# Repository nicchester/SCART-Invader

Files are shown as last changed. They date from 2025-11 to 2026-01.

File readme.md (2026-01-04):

# SCART Invader 

An open-hardware RGB SCART multiplexer with features:

- Auto-detection of a video signal on CVBS, CSYNC, YPbPr, or S-Video
- Aspect ratio (pin 8) and RGB/Composite blanking (pin 16) control 
- Support for CVBS -> CSYNC with LM1881 on board (switched in by a relay) 
- IR remote control 
- Fully isolated relay mux design 
- 100% Through-hole design for tedious hand assembly 
- Ultra-compact design 
- Enclosure printable on most home 3D printers 
- 2-layer PCB design for cheap manufacture by your favourite PCB fabricator

---

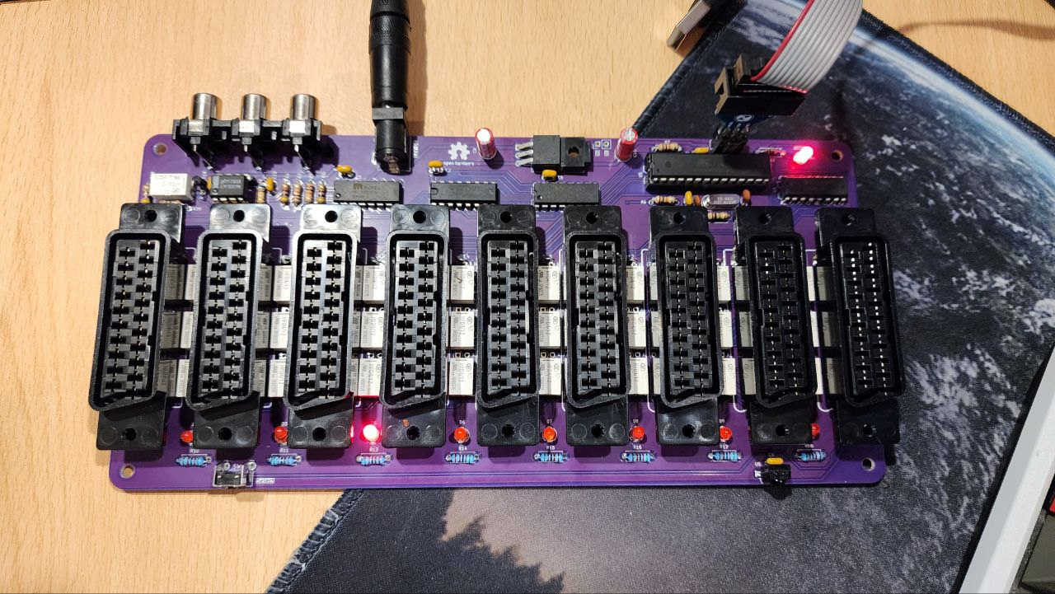
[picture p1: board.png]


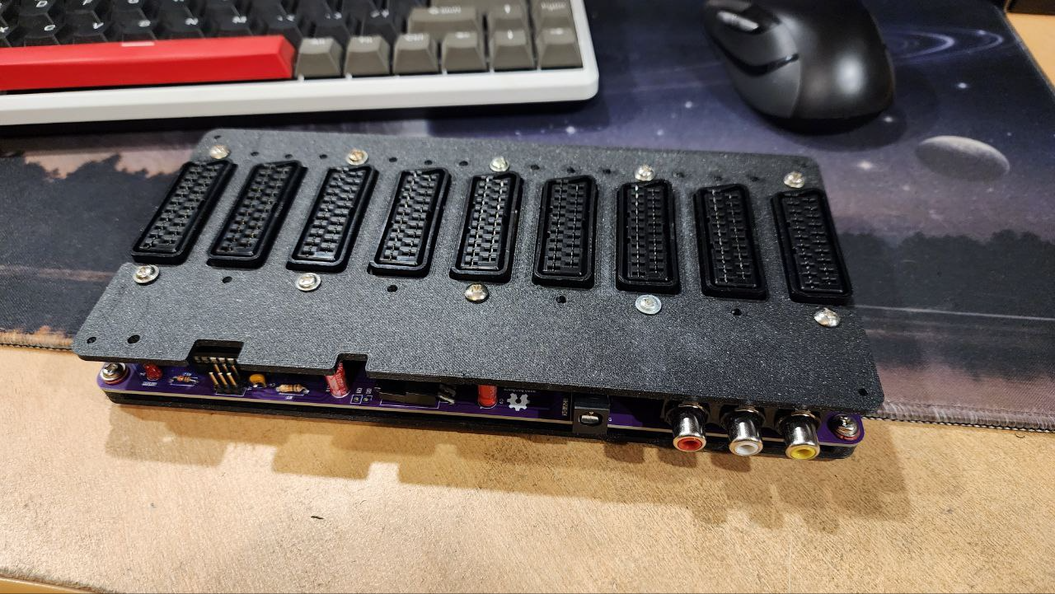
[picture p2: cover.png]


---

### TODOs

- Implement remote control 
- Implement configuration interface over UART

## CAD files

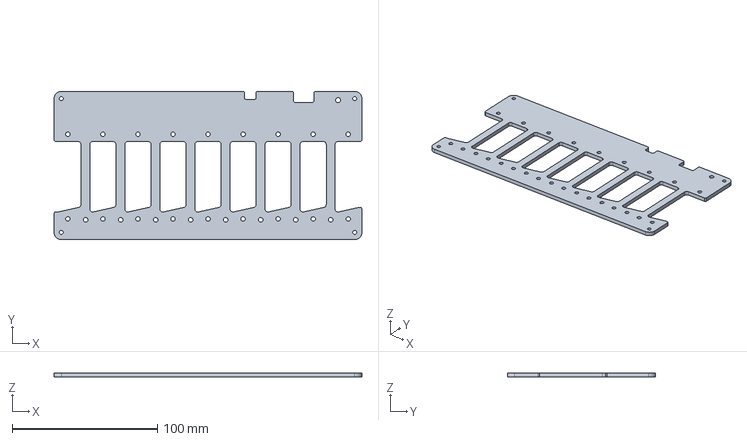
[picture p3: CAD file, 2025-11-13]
Enclosure/Top_Cover.FCStd
212.0 x 102.0 x 3.00 mm

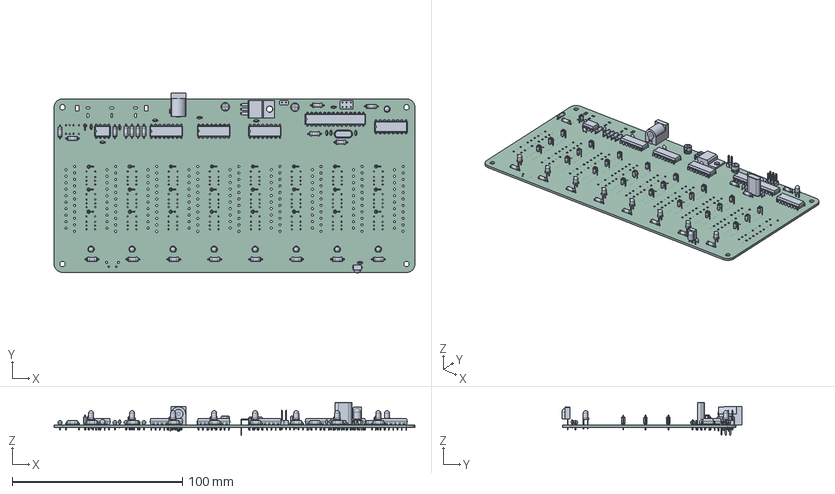
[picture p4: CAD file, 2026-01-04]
PCB/SCART_Invader.step
212.0 x 105.9 x 19.4 mm
D_DO-35_SOD27_P2.54mm_Vertical_AnodeUp x 25
C_Disc_D3.0mm_W1.6mm_P2.50mm x 11
LED_D3.0mm x 9
CP_Radial_D5.0mm_P2.50mm x 2
DIP-8_W7.62mm
BarrelJack_Horizontal
R_Axial_DIN0207_L6.3mm_D2.5mm_P7.62mm_Horizontal x 19
DIP-28_W7.62mm
PinHeader_2x03_P2.54mm_Vertical
DIP-16_W7.62mm x 4
Vishay_MINICAST-3Pin
PinHeader_1x02_P2.54mm_Vertical
Crystal_HC49-U_Vertical
TO-220-3_Horizontal_TabDown
SCART_Invader_PCB

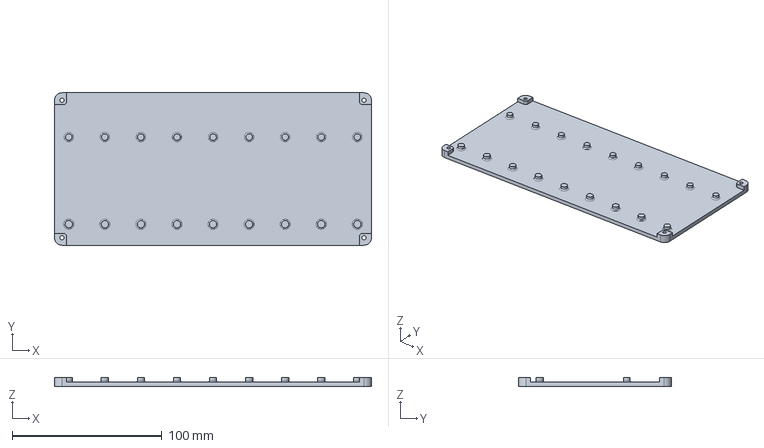
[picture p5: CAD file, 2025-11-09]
Enclosure/Bottom_Cover.FCStd
212.0 x 102.0 x 6.00 mm

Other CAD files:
Enclosure/Top_Cover.stl

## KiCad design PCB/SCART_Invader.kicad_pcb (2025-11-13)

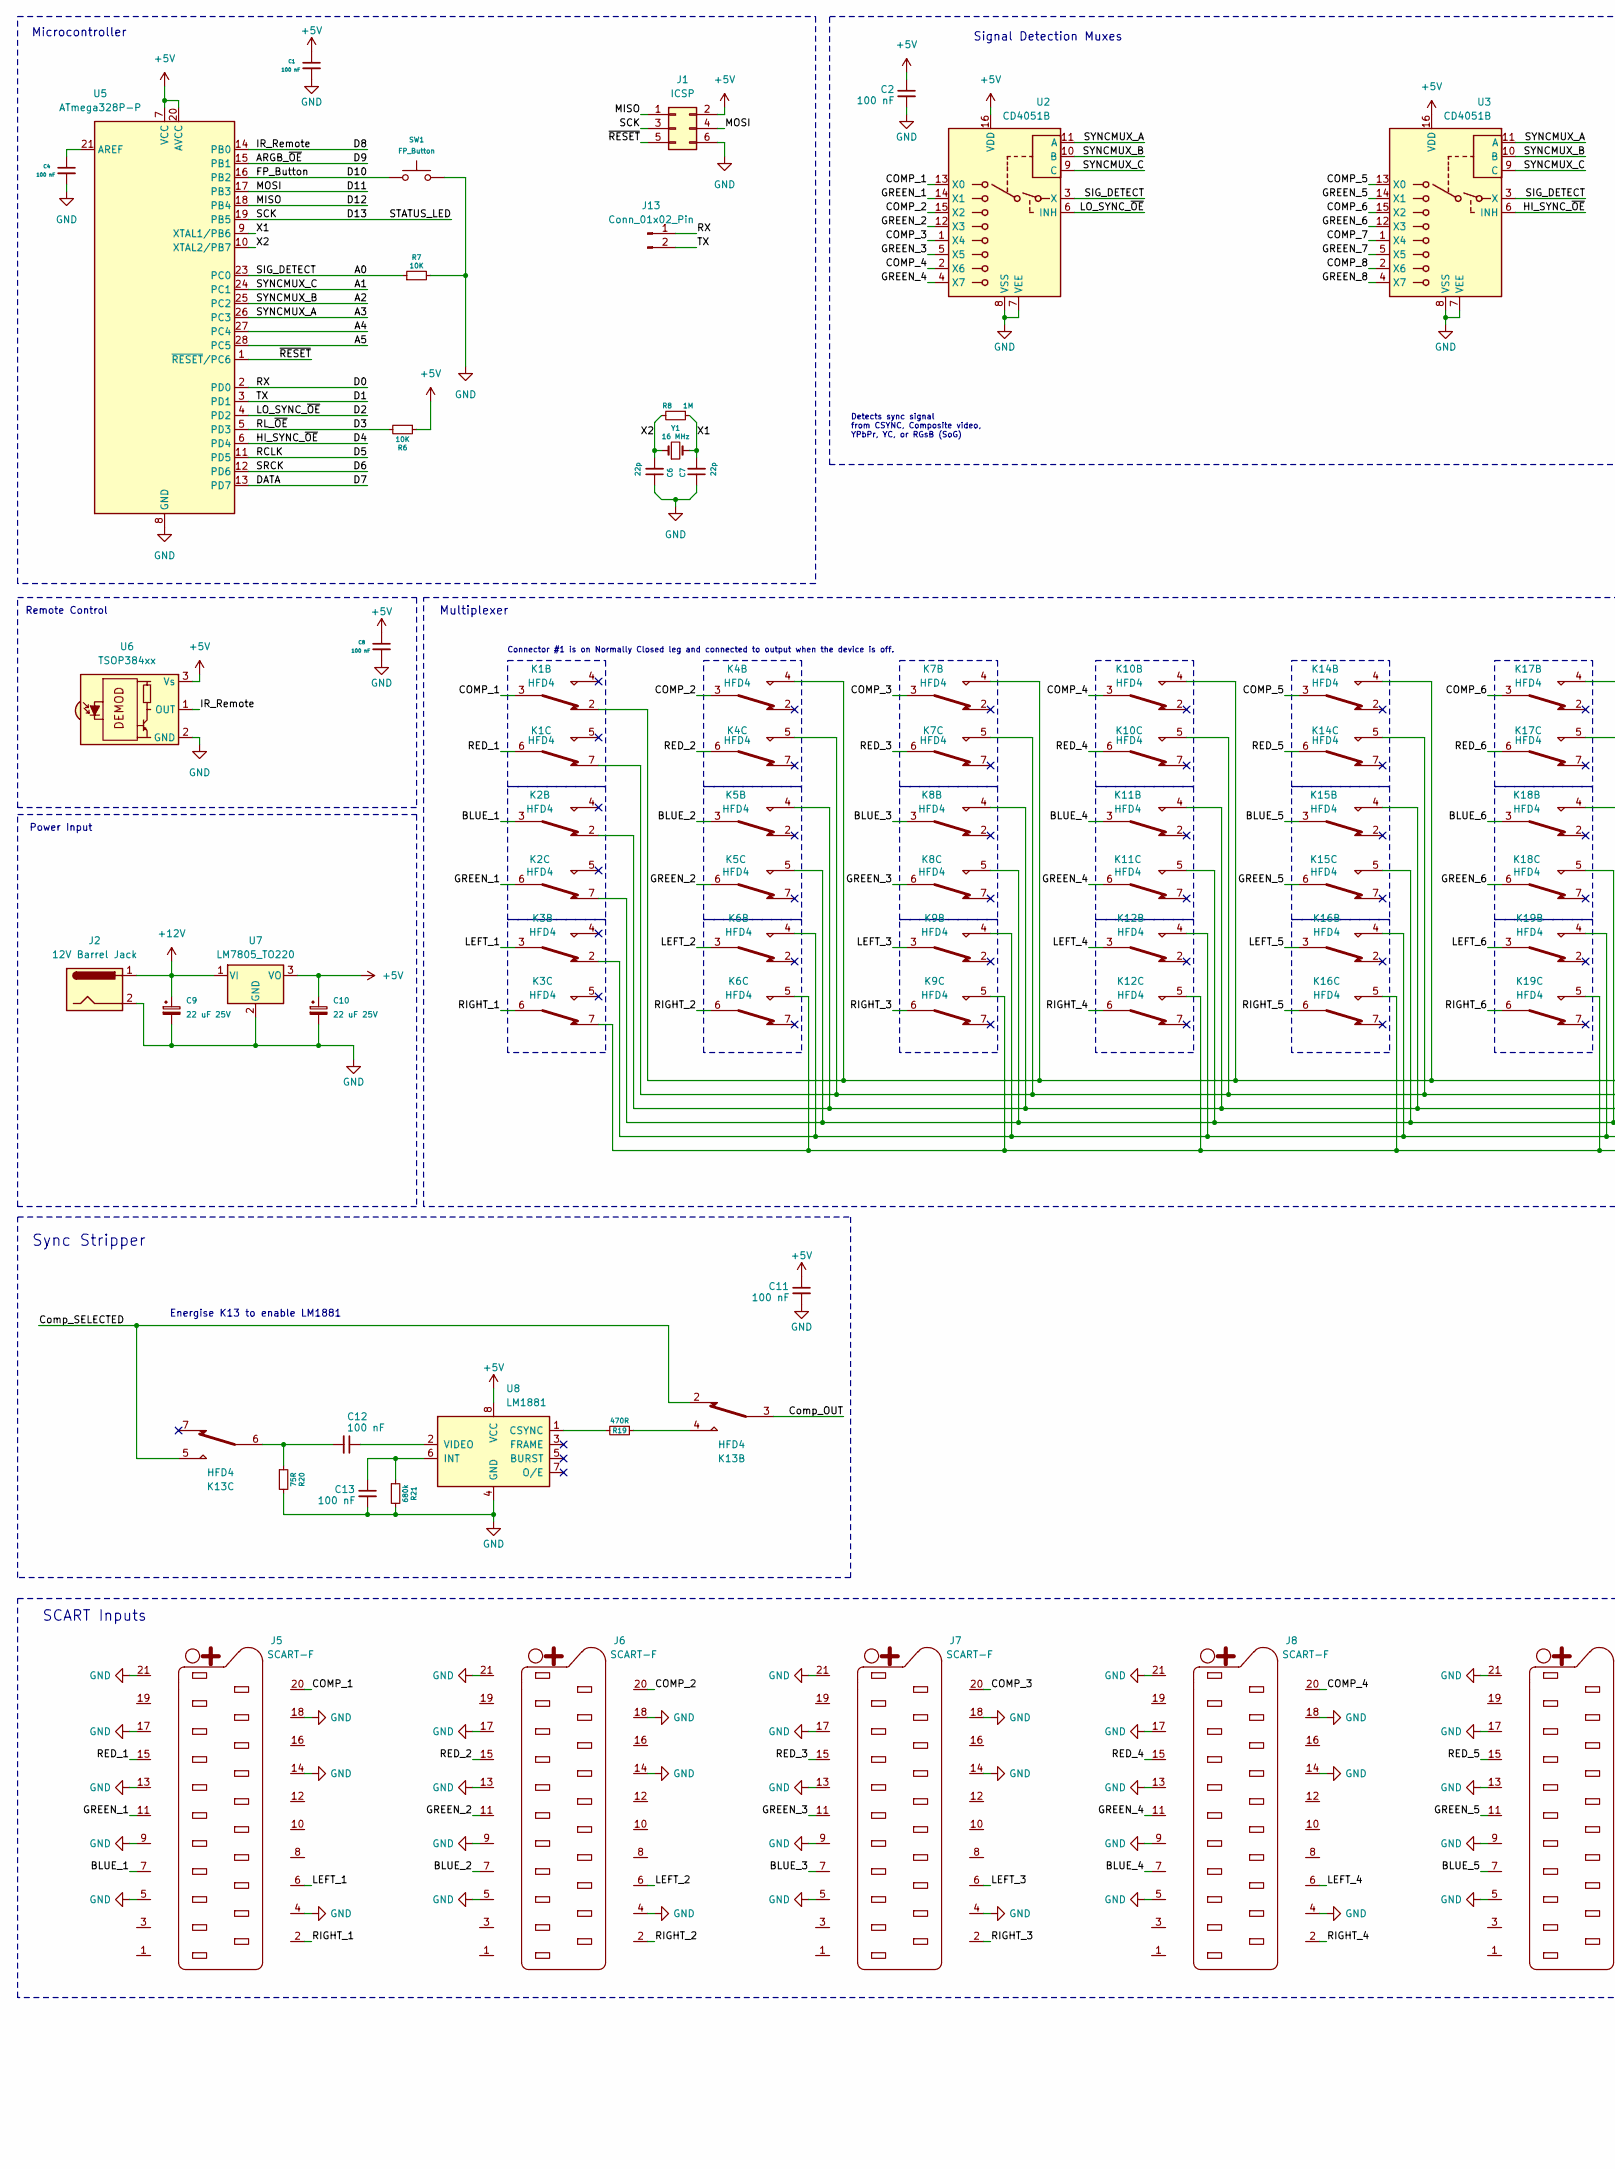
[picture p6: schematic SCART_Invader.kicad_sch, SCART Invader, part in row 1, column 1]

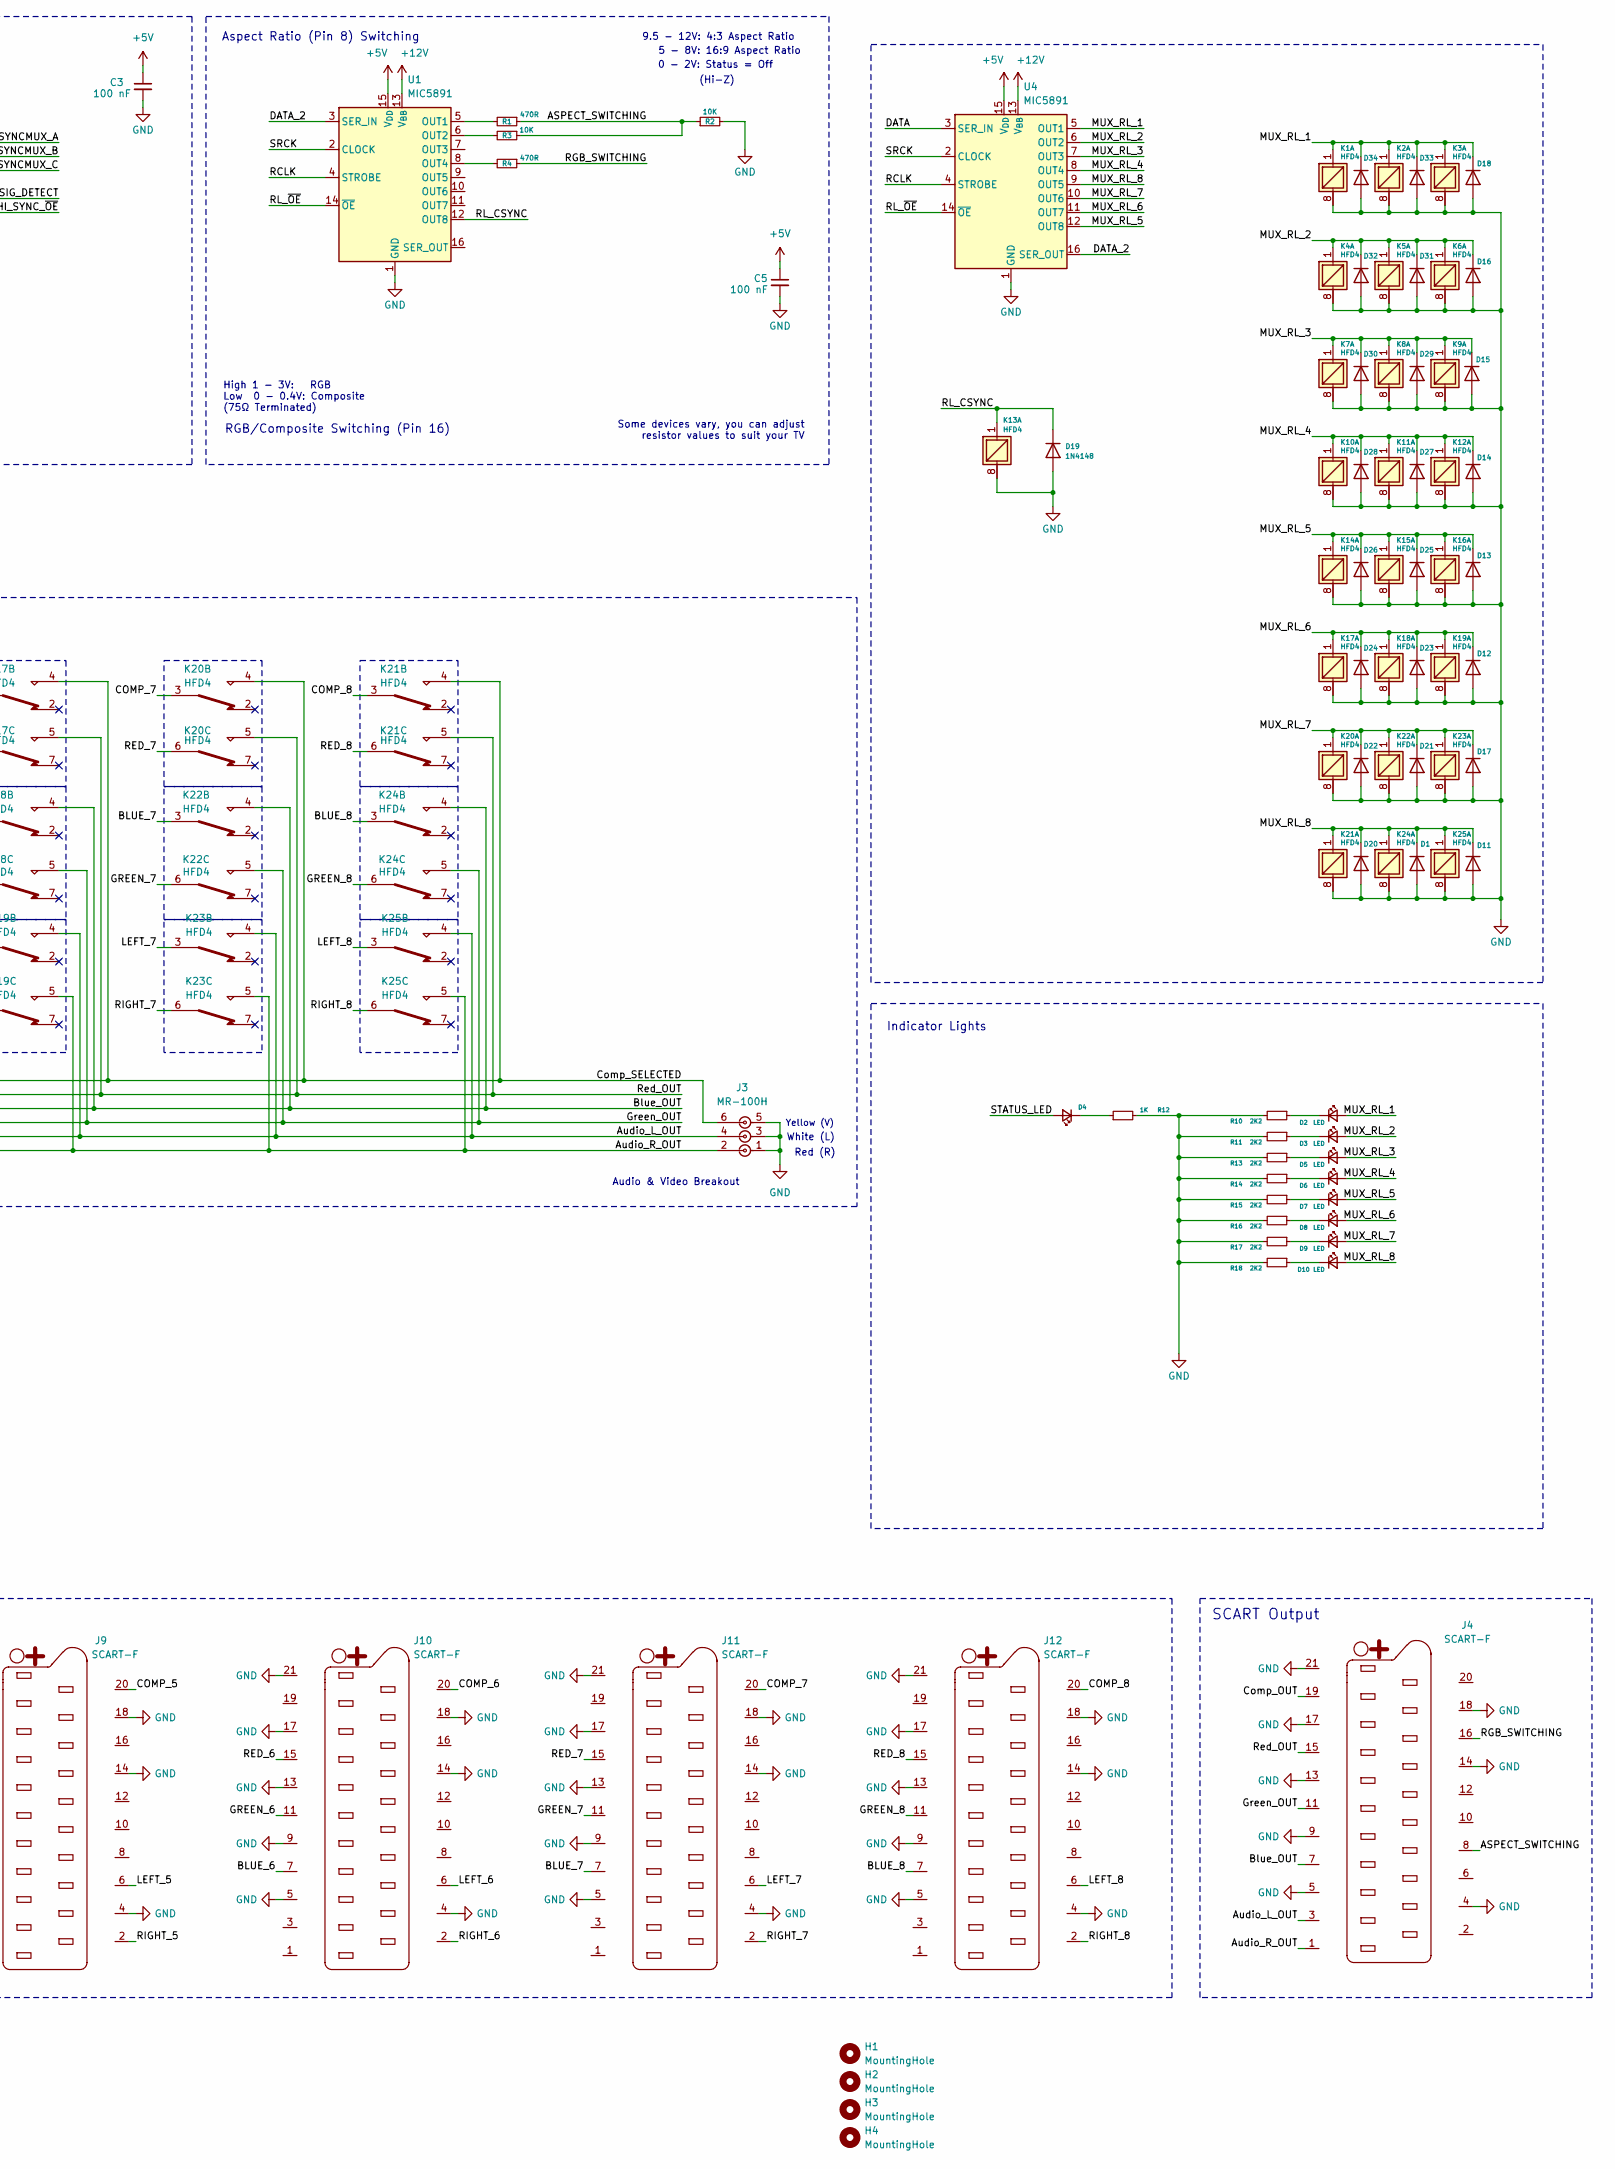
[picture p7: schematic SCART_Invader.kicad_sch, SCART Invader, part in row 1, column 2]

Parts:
C1, C2, C3, C4, C5, C8, C11, C12, C13: 100 nF; C_Disc_D3.0mm_W1.6mm_P2.50mm
C6, C7: 22p; C_Disc_D3.0mm_W1.6mm_P2.50mm
C9, C10: 22 uF 25V; CP_Radial_D5.0mm_P2.50mm
D1, D11, D12, D13, D14, D15, D16, D17, D18, D19, D20, D21, D22, D23, D24, D25, D26, D27, D28, D29, D30, D31, D32, D33, D34: 1N4148; D_DO-35_SOD27_P2.54mm_Vertical_AnodeUp
D2, D3, D5, D6, D7, D8, D9, D10: LED; LED_D3.0mm
D4: Status; LED_D3.0mm
H1, H2, H3, H4: MountingHole; MountingHole_3.2mm_M3
J1: ICSP; PinHeader_2x03_P2.54mm_Vertical
J2: 12V Barrel Jack; BarrelJack_Horizontal
J3: MR-100H; RCJ-32234
J4, J5, J6, J7, J8, J9, J10, J11, J12: SCART-F; SCART_F_Vertical_Wide
J13: Conn_01x02_Pin; PinHeader_1x02_P2.54mm_Vertical
K1, K2, K3, K4, K5, K6, K7, K8, K9, K10, K11, K12, K13, K14, K15, K16, K17, K18, K19, K20, K21, K22, K23, K24, K25: HFD4
R1, R4, R19: 470R; R_Axial_DIN0207_L6.3mm_D2.5mm_P7.62mm_Horizontal
R2, R3, R6, R7: 10K; R_Axial_DIN0207_L6.3mm_D2.5mm_P7.62mm_Horizontal
R8: 1M; R_Axial_DIN0207_L6.3mm_D2.5mm_P7.62mm_Horizontal
R10, R11, R13, R14, R15, R16, R17, R18: 2K2; R_Axial_DIN0207_L6.3mm_D2.5mm_P7.62mm_Horizontal
R12: 1K; R_Axial_DIN0207_L6.3mm_D2.5mm_P7.62mm_Horizontal
R20: 75R; R_Axial_DIN0207_L6.3mm_D2.5mm_P7.62mm_Horizontal
R21: 680k; R_Axial_DIN0207_L6.3mm_D2.5mm_P7.62mm_Horizontal
SW1: FP_Button; SW_Tactile_SKHH_Angled
U1, U4: MIC5891; DIP-16_W7.62mm
U2, U3: CD4051B; DIP-16_W7.62mm
U5: ATmega328P-P; DIP-28_W7.62mm
U6: TSOP384xx; Vishay_MINICAST-3Pin
U7: LM7805_TO220; TO-220-3_Horizontal_TabDown
U8: LM1881; DIP-8_W7.62mm
Y1: 16 MHz; Crystal_HC49-U_Vertical

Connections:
+5V: C1.1, C2.1, C3.1, C5.1, C8.1, C10.1, C11.1, J1.2, R6.1, U1.15 (V_{DD}), U2.16 (VDD), U3.16 (VDD), U4.15 (V_{DD}), U5.7 (VCC), U5.20 (AVCC), U6.3 (Vs), U7.3 (VO), U8.8 (VCC)
+12V: C9.1, J2.1, U1.13 (V_{BB}), U4.13 (V_{BB}), U7.1 (VI)
/A0: R7.1, U2.3 (X), U3.3 (X), U5.23 (PC0)
/A1: U2.9 (C), U3.9 (C), U5.24 (PC1)
/A2: U2.10 (B), U3.10 (B), U5.25 (PC2)
/A3: U2.11 (A), U3.11 (A), U5.26 (PC3)
/A4: U5.27 (PC4)
/A5: U5.28 (PC5)
/ARGB_~OE: U5.15 (PB1)
/ASPECT_SWITCHING: J4.8, R1.1, R2.1, R3.1
/Audio_L_OUT: J3.4, J4.3, K3.2, K6.4, K9.4, K12.4, K16.4, K19.4, K23.4, K25.4
/Audio_R_OUT: J3.2, J4.1, K3.7, K6.5, K9.5, K12.5, K16.5, K19.5, K23.5, K25.5
/BLUE_1: J5.7, K2.3
/BLUE_2: J6.7, K5.3
/BLUE_3: J7.7, K8.3
/BLUE_4: J8.7, K11.3
/BLUE_5: J9.7, K15.3
/BLUE_6: J10.7, K18.3
/BLUE_7: J11.7, K22.3
/BLUE_8: J12.7, K24.3
/Blue_OUT: J4.7, K2.2, K5.4, K8.4, K11.4, K15.4, K18.4, K22.4, K24.4
/COMP_1: J5.20, K1.3, U2.13 (X0)
/COMP_2: J6.20, K4.3, U2.15 (X2)
/COMP_3: J7.20, K7.3, U2.1 (X4)
/COMP_4: J8.20, K10.3, U2.2 (X6)
/COMP_5: J9.20, K14.3, U3.13 (X0)
/COMP_6: J10.20, K17.3, U3.15 (X2)
/COMP_7: J11.20, K20.3, U3.1 (X4)
/COMP_8: J12.20, K21.3, U3.2 (X6)
/Comp_OUT: J4.19, K13.3
/Comp_SELECTED: J3.6, K1.2, K4.4, K7.4, K10.4, K13.2, K13.5, K14.4, K17.4, K20.4, K21.4
/D0: J13.1, U5.2 (PD0)
/D1: J13.2, U5.3 (PD1)
/D2: U2.6 (INH), U5.4 (PD2)
/D3: R6.2, U1.14 (~OE), U4.14 (~OE), U5.5 (PD3)
/D4: U3.6 (INH), U5.6 (PD4)
/D5: U1.4 (STROBE), U4.4 (STROBE), U5.11 (PD5)
/D6: U1.2 (CLOCK), U4.2 (CLOCK), U5.12 (PD6)
/D7: U4.3 (SER_IN), U5.13 (PD7)
/D8: U5.14 (PB0), U6.1 (OUT)
/D10: SW1.1, U5.16 (PB2)
/D11: J1.4, U5.17 (PB3)
/D12: J1.1, U5.18 (PB4)
/D13: D4.2 (A), J1.3, U5.19 (PB5)
/DATA_2: U1.3 (SER_IN), U4.16 (SER_OUT)
/GREEN_1: J5.11, K2.6, U2.14 (X1)
/GREEN_2: J6.11, K5.6, U2.12 (X3)
/GREEN_3: J7.11, K8.6, U2.5 (X5)
/GREEN_4: J8.11, K11.6, U2.4 (X7)
/GREEN_5: J9.11, K15.6, U3.14 (X1)
/GREEN_6: J10.11, K18.6, U3.12 (X3)
/GREEN_7: J11.11, K22.6, U3.5 (X5)
/GREEN_8: J12.11, K24.6, U3.4 (X7)
/Green_OUT: J4.11, K2.7, K5.5, K8.5, K11.5, K15.5, K18.5, K22.5, K24.5
/LEFT_1: J5.6, K3.3
/LEFT_2: J6.6, K6.3
/LEFT_3: J7.6, K9.3
/LEFT_4: J8.6, K12.3
/LEFT_5: J9.6, K16.3
/LEFT_6: J10.6, K19.3
/LEFT_7: J11.6, K23.3
/LEFT_8: J12.6, K25.3
/MUX_RL_1: D2.2 (A), D18.1 (K), D33.1 (K), D34.1 (K), K1.1, K2.1, K3.1, U4.5 (OUT1)
/MUX_RL_2: D3.2 (A), D16.1 (K), D31.1 (K), D32.1 (K), K4.1, K5.1, K6.1, U4.6 (OUT2)
/MUX_RL_3: D5.2 (A), D15.1 (K), D29.1 (K), D30.1 (K), K7.1, K8.1, K9.1, U4.7 (OUT3)
/MUX_RL_4: D6.2 (A), D14.1 (K), D27.1 (K), D28.1 (K), K10.1, K11.1, K12.1, U4.8 (OUT4)
/MUX_RL_5: D7.2 (A), D13.1 (K), D25.1 (K), D26.1 (K), K14.1, K15.1, K16.1, U4.12 (OUT8)
/MUX_RL_6: D8.2 (A), D12.1 (K), D23.1 (K), D24.1 (K), K17.1, K18.1, K19.1, U4.11 (OUT7)
/MUX_RL_7: D9.2 (A), D17.1 (K), D21.1 (K), D22.1 (K), K20.1, K22.1, K23.1, U4.10 (OUT6)
/MUX_RL_8: D1.1 (K), D10.2 (A), D11.1 (K), D20.1 (K), K21.1, K24.1, K25.1, U4.9 (OUT5)
/RED_1: J5.15, K1.6
/RED_2: J6.15, K4.6
/RED_3: J7.15, K7.6
/RED_4: J8.15, K10.6
/RED_5: J9.15, K14.6
/RED_6: J10.15, K17.6
/RED_7: J11.15, K20.6
/RED_8: J12.15, K21.6
/RGB_SWITCHING: J4.16, R4.1
/RIGHT_1: J5.2, K3.6
/RIGHT_2: J6.2, K6.6
/RIGHT_3: J7.2, K9.6
/RIGHT_4: J8.2, K12.6
/RIGHT_5: J9.2, K16.6
/RIGHT_6: J10.2, K19.6
/RIGHT_7: J11.2, K23.6
/RIGHT_8: J12.2, K25.6
/RL_CSYNC: D19.1 (K), K13.1, U1.12 (OUT8)
/Red_OUT: J4.15, K1.7, K4.5, K7.5, K10.5, K14.5, K17.5, K20.5, K21.5
/X1: C7.2, R8.1, U5.9 (XTAL1/PB6), Y1.2
/X2: C6.2, R8.2, U5.10 (XTAL2/PB7), Y1.1
/~RESET: J1.5, U5.1 (~RESET/PC6)
GND: C1.2, C2.2, C3.2, C4.2, C5.2, C6.1, C7.1, C8.2, C9.2, C10.2, C11.2, C13.2, D1.2 (A), D11.2 (A), D12.2 (A), D13.2 (A), D14.2 (A), D15.2 (A), D16.2 (A), D17.2 (A), D18.2 (A), D19.2 (A), D20.2 (A), D21.2 (A), D22.2 (A), D23.2 (A), D24.2 (A), D25.2 (A), D26.2 (A), D27.2 (A), D28.2 (A), D29.2 (A), D30.2 (A), D31.2 (A), D32.2 (A), D33.2 (A), D34.2 (A), J1.6, J2.2, J3.1, J3.3, J3.5, J4.4, J4.5, J4.9, J4.13, J4.14, J4.17, J4.18, J4.21, J5.4, J5.5, J5.9, J5.13, J5.14, J5.17, J5.18, J5.21, J6.4, J6.5, J6.9, J6.13, J6.14, J6.17, J6.18, J6.21, J7.4, J7.5, J7.9, J7.13, J7.14, J7.17, J7.18, J7.21, J8.4, J8.5, J8.9, J8.13, J8.14, J8.17, J8.18, J8.21, J9.4, J9.5, J9.9, J9.13, J9.14, J9.17, J9.18, J9.21, J10.4, J10.5, J10.9, J10.13, J10.14, J10.17, J10.18, J10.21, J11.4, J11.5, J11.9, J11.13, J11.14, J11.17, J11.18, J11.21, J12.4, J12.5, J12.9, J12.13, J12.14, J12.17, J12.18, J12.21, K1.8, K2.8, K3.8, K4.8, K5.8, K6.8, K7.8, K8.8, K9.8, K10.8, K11.8, K12.8, K13.8, K14.8, K15.8, K16.8, K17.8, K18.8, K19.8, K20.8, K21.8, K22.8, K23.8, K24.8, K25.8, R2.2, R7.2, R10.2, R11.2, R12.2, R13.2, R14.2, R15.2, R16.2, R17.2, R18.2, R20.2, R21.2, SW1.2, U1.1 (GND), U2.7 (VEE), U2.8 (VSS), U3.7 (VEE), U3.8 (VSS), U4.1 (GND), U5.8 (GND), U5.22 (GND), U6.2 (GND), U7.2 (GND), U8.4 (GND)
unnamed: C12.2, K13.6, R20.1
unnamed: D2.1 (K), R10.1
unnamed: D3.1 (K), R11.1
unnamed: D4.1 (K), R12.1
unnamed: D5.1 (K), R13.1
unnamed: D6.1 (K), R14.1
unnamed: D7.1 (K), R15.1
unnamed: D8.1 (K), R16.1
unnamed: D9.1 (K), R17.1
unnamed: D10.1 (K), R18.1
unnamed: K13.4, R19.1
unnamed: R1.2, U1.5 (OUT1)
unnamed: R3.2, U1.6 (OUT2)
unnamed: R4.2, U1.8 (OUT4)
unnamed: C4.1, U5.21 (AREF)
unnamed: R19.2, U8.1 (CSYNC)
unnamed: C13.1, R21.1, U8.6 (INT)
unnamed: C12.1, U8.2 (VIDEO)

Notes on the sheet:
Microcontroller
0 - 2V: Status = Off
Sync Stripper
Remote Control
9.5 - 12V: 4:3 Aspect Ratio
SCART Output
(Hi-Z)
Detects sync signal from CSYNC, Composite video, YPbPr, YC, or RGsB (SoG)
Energise K13 to enable LM1881
Audio & Video Breakout
Yellow (V)
5 - 8V: 16:9 Aspect Ratio
Power Input
High 1 - 3V: RGB Low 0 - 0.4V: Composite (75Ω Terminated)
Some devices vary, you can adjust resistor values to suit your TV
Multiplexer
Red (R)
Connector #1 is on Normally Closed leg and connected to output when the device is off.
RGB/Composite Switching (Pin 16)
SCART Inputs
Indicator Lights
White (L)
Aspect Ratio (Pin 8) Switching
Signal Detection Muxes

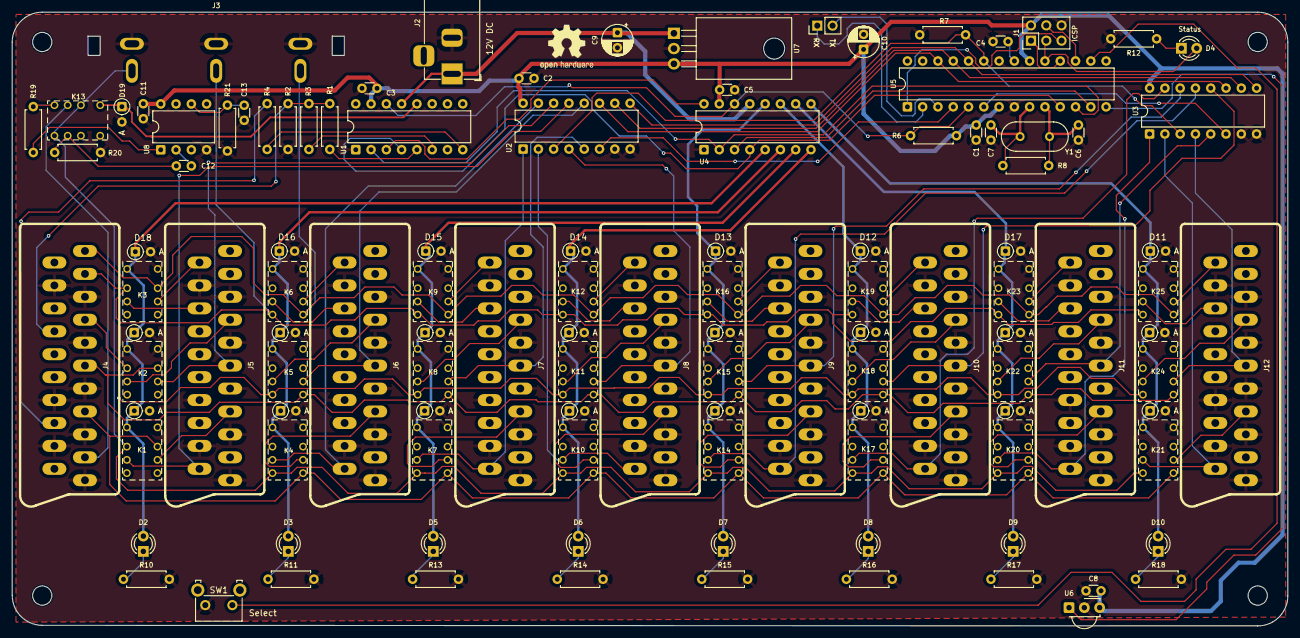
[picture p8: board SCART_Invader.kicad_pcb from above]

Board: 2 copper layers, 212.0 x 102.0 mm, 118 parts (0 on the bottom side), 108 nets.

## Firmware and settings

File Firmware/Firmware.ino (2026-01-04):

#include <EEPROM.h>
#include <IRremote.h> 
#include "defs.h"

// AVRDude Command I used to burn firmware with USBasp (for future reference)
// sudo avrdude -c usbasp -p m328p -U flash:w:Firmware.ino.with_bootloader.standard.hex:i 

// Represents the state of the first shift register (relay driver) 
byte output = 0x0; 

// Byte representing state of the second shift register (Status & RGB signal via a resistor ladder) 
byte statusMode = STATUS_OFF; 

// Time since the front panel button was pressed 
unsigned long lastManualSwitch = 0; 

// Channel selected on the solid state muxes 
byte muxChannel = 0; 

// Channel selected on the AV multiplexer 
byte selectedChannel = 0; 

// Whether an input is locked on 
bool lock = false; 

// Whether the device is in 'auto' mode 
bool autoMode = true;

// Last time a 'valid' voltage was seen on the current auto-detected channel 
unsigned long lastSignalDetect; 


// Last time the status LED blinked in 'search' mode 
unsigned long lastBlinkMillis = 0; 

// state of the status LED
unsigned long statusLedOn = true; 

// IR decoder stuff 
IRrecv irrecv(IR_REMOTE);
decode_results results;

/* Selects input on sync muxes */
void syncSelect(byte channel)
{  
  digitalWrite(SYNCMUX_A,     channel & 0b0001); 
  digitalWrite(SYNCMUX_B,     channel & 0b0010); 
  digitalWrite(SYNCMUX_C,     channel & 0b0100); 
  digitalWrite(_HI_SYNC_OE, !(channel & 0b1000)); 
  digitalWrite(_LO_SYNC_OE,   channel & 0b1000);
}

// Detect an incoming analog signal (muxes must be set first)
bool detectSignal()
{
  // 40 millisecond detection period 
  unsigned long endtime = millis() + 40; 
  bool result = false; 
  int adcVal = 0; 

  while(millis() < endtime)
  {
    adcVal = analogRead(SIG_DETECT);
    if(adcVal > 10)
      result = true; 
  }

  return result; 
}

// Shifts out data to relay driver and aspect ratio/RGB switching registers 
void updateOutput()
{
  digitalWrite(RCLK, LOW);
  shiftOut(DATA, SRCK, MSBFIRST, statusMode); 
  shiftOut(DATA, SRCK, MSBFIRST, output); 
  digitalWrite(RCLK, HIGH); 
}

// Flip the output enable 
void enableOutput(bool enable)
{
  digitalWrite(_RL_OE, !enable); 
}

void selectChannel(byte channel)
{
  // Get the status byte out of the EEPROM 
  statusMode = EEPROM.read(EEPROM_CHANNEL_MODES_BASE + channel); 

  // Update the output byte 
  output = rlBytes[channel]; 

  // Write out the data 
  updateOutput(); 
}

// Check EEPROM for magic number indicating first run
void checkEEPROM()
{
  if (EEPROM.read(EEPROM_MAGIC_ADDR) != EEPROM_MAGIC) 
  {

    for(int i = 0; i <= 8; i++)
    {
      EEPROM.write(EEPROM_CHANNEL_MODES_BASE + i, defaultChannelStates[i]); 
    }

    // Write magic number 
    EEPROM.write(EEPROM_MAGIC_ADDR, EEPROM_MAGIC);
  }
}

void setup() 
{
  Serial.begin(115200); 
  Serial.println("Play SCART Invaders! Happy Gaming!"); 

  checkEEPROM(); 

  irrecv.enableIRIn(); // Start the receiver
  
  /* Set mode of all I/O pins */
  pinMode(RCLK, OUTPUT); 
  pinMode(SRCK, OUTPUT); 
  pinMode(DATA, OUTPUT); 
  pinMode(_RL_OE, OUTPUT);

  pinMode(_LO_SYNC_OE, OUTPUT); 
  pinMode(_HI_SYNC_OE, OUTPUT); 

  pinMode(IR_REMOTE, INPUT); 
  pinMode(FP_BUTTON, INPUT_PULLUP); 
  pinMode(STATUS_LED, OUTPUT); 

  pinMode(SIG_DETECT, INPUT); 
  pinMode(SYNCMUX_A, OUTPUT); 
  pinMode(SYNCMUX_B, OUTPUT); 
  pinMode(SYNCMUX_C, OUTPUT); 

  /* Set output enable/inhibit pins initially high */
  digitalWrite(_RL_OE, HIGH); 
  digitalWrite(_LO_SYNC_OE, HIGH); 
  digitalWrite(_HI_SYNC_OE, HIGH); 

  output = rlBytes[0]; 
  statusMode = STATUS_OFF; 
  updateOutput(); 
  enableOutput(true); 

  lastManualSwitch = millis(); 

  digitalWrite(STATUS_LED, LOW); 

}

// Blink status LED a given number of times 
// to confirm an action via remote 
void blinkConfirm(byte blinks) 
{
  digitalWrite(STATUS_LED, LOW); 
  delay(1000);

  for(int i = 0; i < blinks; i++)
  {
    digitalWrite(STATUS_LED, HIGH); 
    delay(100);
    digitalWrite(STATUS_LED, LOW); 
    delay(100); 
  }
  
  delay(900);
}

// Blink the status led when not locked to an input, or steady when locked 
void blinkStatus()
{
  unsigned long currentMillis; 
  
  // If the device is set to an input then show a steady status light 
  if(!autoMode || lock)
  {
    digitalWrite(STATUS_LED, HIGH); 
  }
  // Otherwise it blinks 
  else
  {
    currentMillis = millis();

    if (currentMillis - lastBlinkMillis >= 1000) 
    {
      lastBlinkMillis = currentMillis;
  
      statusLedOn = !statusLedOn;
      digitalWrite(STATUS_LED, statusLedOn);
    }
    
  }
}

void stepChannel(bool up)
{
    unsigned long currentMillis = millis(); 
    if(currentMillis - lastManualSwitch >= DEBOUNCE_TIME)
    {
      delay(100); 

      // Switch out of auto mode and remove lock
      autoMode = false; 
      lock = false; 

      if(up)
      {
        // Increment the target channel 
        selectedChannel++; 

        // If we overflow the number of channels, 
        // go back to zero indicating no selection on the AV mux 
        if(selectedChannel > 8) selectedChannel = 0; 
      }
      else
      {
        if(selectedChannel == 0)
        {
          selectedChannel = 8; 
        }
        else
        {
          selectedChannel--; 
        }
      }

      // If channel is zero then set output off and enable 'auto' mode, 
      // else update and enable the output 
      if(selectedChannel == 0) 
      {
        autoMode = true; 
      }

      selectChannel(selectedChannel); 

      delay(100); 
      lastManualSwitch = millis(); 
    }
}

void changeChannelManual(byte channel)
{
    unsigned long currentMillis = millis(); 
    if(currentMillis - lastManualSwitch >= DEBOUNCE_TIME)
    {
      delay(100); 

      // Switch out of auto mode and remove lock
      autoMode = false; 
      lock = false; 

      selectedChannel = channel; 

      // If channel is zero then set output off and enable 'auto' mode, 
      // else update and enable the output 
      if(selectedChannel == 0) 
      {
        autoMode = true; 
      }

      selectChannel(selectedChannel); 

      delay(100); 
      lastManualSwitch = millis(); 
    }
}

// Cycle aspect ratio 
void changeAspectRatio()
{
  // Return if we're on zero, output should be disabled in search mode 
  if(selectedChannel == 0)
    return; 

  // if wide then switch to 4:3 
  if(statusMode & ASP_WIDE)
  {
    statusMode &= ~ASP_WIDE;
    statusMode |= ASP_NORMAL; 

    blinkConfirm(2); 
  }
  // if 4:3 then switch to off
  else if(statusMode & ASP_NORMAL)
  {
    statusMode &= ~ASP_WIDE; 
    statusMode &= ~ASP_NORMAL; 

    blinkConfirm(1); 
  }
  // if off then switch to wide 
  else
  {
    statusMode |= ASP_WIDE; 

    blinkConfirm(3); 
  }

  updateOutput(); 

  // Update the EEPROM with the channel mode 
  EEPROM.update(EEPROM_CHANNEL_MODES_BASE + selectedChannel, statusMode); 
}

// Toggle RGB/CVBS
void changeRGB()
{
  if(selectedChannel == 0)
    return; 

    // switch between RGB and no RGB 
    statusMode ^= MODE_RGB;

    if(statusMode & MODE_RGB)
      blinkConfirm(2); 
    else
      blinkConfirm(1); 

    updateOutput(); 

    EEPROM.update(EEPROM_CHANNEL_MODES_BASE + selectedChannel, statusMode); 
}

// Toggle LM1881 sync stripper 
void changeCSYNC()
{
  if(selectedChannel == 0)
    return; 

  // Switch CSYNC on/off 
  statusMode ^= MODE_CSYNC;

  if(statusMode & MODE_CSYNC)
    blinkConfirm(2); 
  else
    blinkConfirm(1); 

  updateOutput(); 

  EEPROM.update(EEPROM_CHANNEL_MODES_BASE + selectedChannel, statusMode); 
}

void handleAutoMode()
{
  unsigned long currentMillis = millis();
  bool signalDetected = false;  

  // Return if we're not outside of the grace period after user manually switching
  if(currentMillis - lastManualSwitch <= MANUAL_TIMEOUT)
  {
    return; 
  }
  
  // Select channel using the solid state muxes
  syncSelect(muxChannel); 

  // If the device is currently auto-locked to an input, 
  // check if the signal has disappeared after a given timeout 
  if(lock)
  {
    currentMillis = millis(); 
    // Check if a signal is still detected, if so store the time it was seen
    signalDetected = detectSignal(); 
    if(signalDetected) lastSignalDetect = millis(); 
    
    // If we no longer detect a signal, and the grace period is satisfied, then remove the lock and disable output 
    if(!signalDetected && currentMillis - lastSignalDetect >= SIG_TIMEOUT)
    {      
      lock = false; 
      delay(100); 
      selectedChannel = 0; 
      selectChannel(selectedChannel); 
    }
  }
  else
  {
    // Else, check for a valid signal on the current input of the sync mux. 
    currentMillis = millis(); 
    if(detectSignal())
    {
      lastSignalDetect = millis(); 
      lock = true; 
      selectedChannel = (muxChannel / 2) + 1; 
      selectChannel(selectedChannel); 
      delay(100); 
    }
    else
    {
      muxChannel++; 

      if(muxChannel > 15) muxChannel = 0; 
    }
  } 
}

void handleIR()
{
  unsigned long currentMillis = millis(); 

  if (irrecv.decode(&results))
  {
    if(currentMillis - lastManualSwitch >= DEBOUNCE_TIME)
    {
      switch(results.value)
      {
        case BUTTON_1:
          changeChannelManual(1);
          break; 

        case BUTTON_2:
          changeChannelManual(2);
          break; 

        case BUTTON_3:
          changeChannelManual(3);
          break; 

        case BUTTON_4:
          changeChannelManual(4);
          break; 

        case BUTTON_5:
          changeChannelManual(5);
          break; 

        case BUTTON_6:
          changeChannelManual(6);
          break; 

        case BUTTON_7:
          changeChannelManual(7);
          break; 

        case BUTTON_8:
          changeChannelManual(8);
          break; 

        case BUTTON_0:
          changeChannelManual(0);
          break; 

        case CH_UP:
          stepChannel(true);
          break; 

        case CH_DOWN:
          stepChannel(false);
          break;

        case BUTTON_RED: 
          changeAspectRatio(); 
          break; 

        case BUTTON_GREEN: 
          changeRGB(); 
          break;

        case BUTTON_YELLOW:
          changeCSYNC(); 
          break; 

        default:
          Serial.print("Unknown IR command: 0x");
          Serial.println(results.value, HEX); 
          break; 
      }
    }

    lastManualSwitch = millis();
    irrecv.resume();
  }
}

void loop() 
{
  blinkStatus(); 
  
  if(autoMode)
  {
    handleAutoMode(); 
  }

  handleIR(); 

  // If the front panel button is pressed then increment the current channel 
  if(!digitalRead(FP_BUTTON))
  {
    stepChannel(true); 
  }
  
}

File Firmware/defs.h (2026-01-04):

/* Pin definitions */

#define IR_REMOTE   8 
#define FP_BUTTON   10
#define STATUS_LED  13

#define SIG_DETECT  A0
#define SYNCMUX_A   A3 
#define SYNCMUX_B   A2
#define SYNCMUX_C   A1

#define _LO_SYNC_OE 2
#define _RL_OE      3
#define _HI_SYNC_OE 4
#define RCLK        5
#define SRCK        6
#define DATA        7

/* EEPROM Stuff */

// If the magic number 42 is not at this address, default states will be written to the EEPROM
#define EEPROM_MAGIC_ADDR 0x0
#define EEPROM_MAGIC 42 

// Base address of EEPROM aspect ratio/RGB/CVBS/SYNC configuration bytes
#define EEPROM_CHANNEL_MODES_BASE 0x01

/* Define remote control codes */

#define BUTTON_1 0x10 
#define BUTTON_2 0x810
#define BUTTON_3 0x410
#define BUTTON_4 0xC10
#define BUTTON_5 0x210 
#define BUTTON_6 0xA10
#define BUTTON_7 0x610 
#define BUTTON_8 0xE10 
#define BUTTON_9 0x110
#define BUTTON_0 0x910

#define BUTTON_RED      0x338 // use to toggle 16:9, 4:3 etc 
#define BUTTON_GREEN    0xB38 // use to toggle CVBS, RGB
#define BUTTON_YELLOW   0x738 // use to toggle CSYNC or CVBS 
#define BUTTON_BLUE     0xF38 // dunno 

#define CH_UP   0x90
#define CH_DOWN 0x890

/* Define bytes for relay driver shift register */
const byte rlBytes[] = 
{
  0b00000001, // No Selection
  0b00000000, // Ch1 
  0b00000011, // Ch2
  0b00000101, // Ch3
  0b00001001, // Ch4
  0b10000001, // Ch5
  0b01000001, // Ch6
  0b00100001, // Ch7
  0b00010001, // Ch8
}; 

/* Aspect ratio and RGB switching shift register bytes */
const byte ASP_WIDE   = 0b00000010; // Force 16:9 aspect ratio 
const byte ASP_NORMAL = 0b00000001; // Force 4:3 aspect ratio 
const byte STATUS_OFF = 0b00000000; // No output at all
const byte MODE_RGB   = 0b00001000; // Fast RGB switching enabled, forces TV to RGB video
const byte MODE_CVBS  = 0b00000000; // No fast RGB switching; may switch TV to composite video
const byte MODE_CSYNC = 0b10000000; // Switch CVBS via to LM1881 sync cleaner 

// Default states that will be written to EEPROM on first boot
const byte defaultChannelStates[] = 
{
  STATUS_OFF, 
  ASP_NORMAL | MODE_CSYNC | MODE_RGB, 
  ASP_NORMAL | MODE_CSYNC | MODE_RGB,
  ASP_NORMAL | MODE_CSYNC | MODE_RGB,
  ASP_NORMAL | MODE_CSYNC | MODE_RGB,
  ASP_NORMAL | MODE_CSYNC | MODE_RGB,
  ASP_NORMAL | MODE_CSYNC | MODE_RGB,
  ASP_NORMAL | MODE_CSYNC | MODE_RGB,
  ASP_NORMAL | MODE_CSYNC | MODE_RGB,
}; 

// Debounce period for select button 
const unsigned long DEBOUNCE_TIME = 100; 

// Timeout for an auto AV signal (milliseconds)
const unsigned long SIG_TIMEOUT = 3000; 

// Timeout after manual switching 
const unsigned long MANUAL_TIMEOUT = 5000; 

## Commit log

2025-11-09 Adds project files and readme
    [Bottom_Cover.FCStd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]
2025-11-09 Fixes bug where the device will lock onto a detected signal too quickly while switching through 'auto' mode
    [Firmware.ino]
2025-11-13 Updates readme, adds top cover
    [SCART_Invader.kicad_pcb, SCART_Invader.kicad_sch, Top_Cover.FCStd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]
2026-01-04 Updates top cover
    [SCART_Invader.step, Top_Cover.FCStd, Top_Cover.stl]
2026-01-04 Fixes remote not working, adds blink on status LED to confirm mode switches
    [Firmware.ino]
